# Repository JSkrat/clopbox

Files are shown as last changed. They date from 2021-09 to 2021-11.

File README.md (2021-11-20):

# clopbox
multiple power pwm outputs controlled with uart with runtime configurable waveform generators

## AVR fuses

By default only 3 outputs are working, so it is necessary to 

## Windows UART setup for speed

Device manager -> usb serial port -> properties -> port settings -> advanced -> BM options -> Latency timer -> set to minimum 1ms

This will reduce latency between actual response on uart and waitForReadyRead call in serialthread.cpp so minimal request period 
is about 8ms.

## The program can't start because Qt5Core.dll is missing from your computer.

Edit the system environment variables -> Environment Variables -> edit Path -> add `C:\Qt\5.12.5\mingw73_64\bin`

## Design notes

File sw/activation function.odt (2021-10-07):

Output power during the half period

Linear functions are boring, let’s curve it like that:

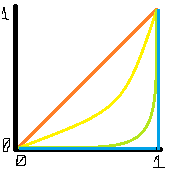
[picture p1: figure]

1. f(x) = x
2. …

### Rounding the curve

Let’s start from circle equation

left lbrace binom{x = r sin( %ialpha )}{y = r cos (%ialpha)} right rbrace

Move circle up

left lbrace binom{x = r sin(%ialpha)}{y = r - r cos(%ialpha)} right rbrace, %ialpha in [ %tau/2; %tau/4 ]

Convert into single function (red graph)

stack{sin( %ialpha ) = x/r; #
%ialpha = arcsin(x/r) #
y = r - r cos(arcsin(x/r)) #
cos(%ialpha ) = sqrt{ 1 - sin(%ialpha)^2 } #
y = r - r sqrt{ 1 - (x/r)^2 }
}

Let’s find the middle part of the curve we’re interested in (intersection with green line)

stack{
y = r - r sqrt{1 - (x/r)^2} intersection y = r - x #
r - r sqrt{1 - (x/r)^2} = r - x #
x = r sqrt{1 - (x/r)^2} #
x = sqrt{ r^2 - x^2 } #
x^2 = r^2 - x^2 #
2x^2 = r^2 #
x = r/sqrt2
}

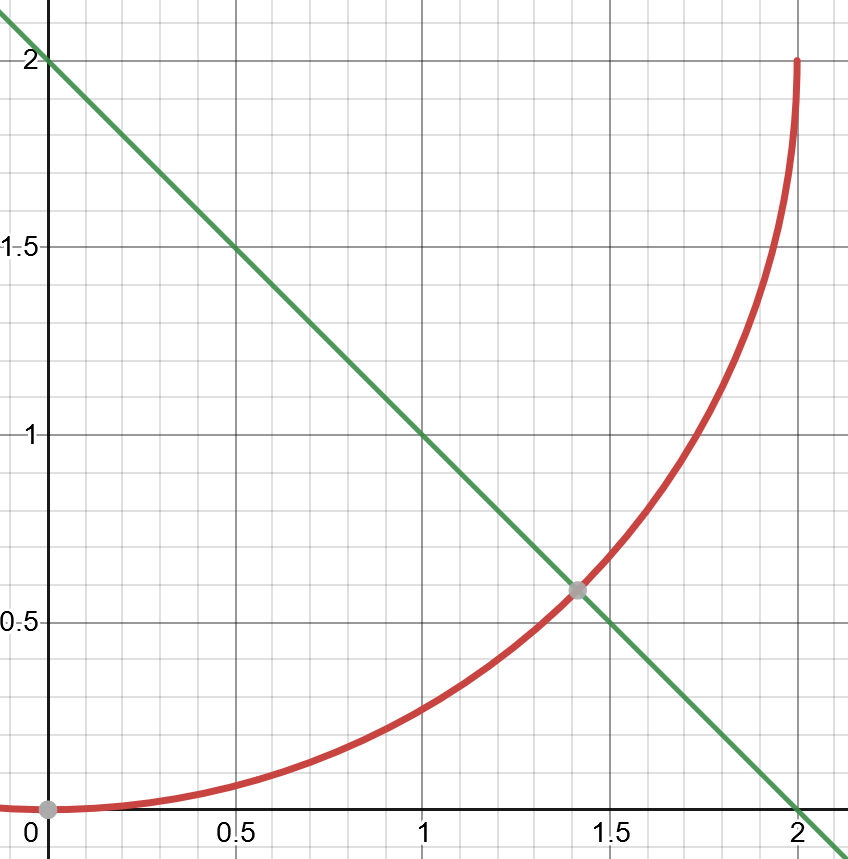
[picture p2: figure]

Apparently we don’t care about that intersection.

Intersection with y = x – b (yellow line)
stack{
y = r - r sqrt{1 - (x/r)^2} intersection y = x - b #
r - r sqrt{1 - (x/r)^2} = x - b #
r sqrt{ 1 - (x/r)^2 } = r + b - x #
r^2( 1 - (x/r)^2 ) = ( r+b )^2 - 2x( r+b ) + x^2 #
r^2 - x^2 = r^2 + 2rb + b^2 - 2xr - 2xb + x^2 #
2x^2 -2xb - 2xr + 2rb + b^2 = 0 #
2x^2 - 2x( r+b ) + (2rb+b^2) = 0 #
A = 2; B = -2r - 2b; C = 2rb + b^2 #
D = B^2 -4AC = 4( r+b )^2 - 4( 2 times (2rb + b^2) ) =
4r^2 + 8rb + 4b^2 - 16rb -8b^2 #
D = 4r^2 - 8rb - 4b^2 #
x_1,2 = {-B +-sqrt D}over {2A} #
x_1 = { 2r + 2b - sqrt{4r^2 - 8rb - 4b^2} } over 4 = 0.5r + 0.5b - 0.25sqrt{4r^2 - 8rb - 4b^2} #
x_2 = { 2r + 2b + sqrt{4r^2 - 8rb - 4b^2} } over 4 = 0.5r + 0.5b + 0.25sqrt{4r^2 - 8rb - 4b^2}

}

We need that line to intersect two points at distance exactly 1:

stack {
x_2 - x_1 = 1 #
0.5sqrt{4r^2 - 8rb - 4b^2} = 1 #
sqrt{4r^2 - 8rb - 4b^2} = 2 #
4r^2 - 8rb - 4b^2 = 4 #
4b^2 + 8rb - 4r^2 + 4 = 0 #
A = 4; B = 8r; C = 4 - 4r^2 #
D = 64r^2 - 4 times 4 times ( 4 - 4r^2 ) = 64r^2 - 64 + 64r^2 = 128r^2 - 64 #
b = {-8r +- sqrt{ 128r^2 - 64 }} over { 8 } = -r +- sqrt{ 2r^2 - 1 }
}

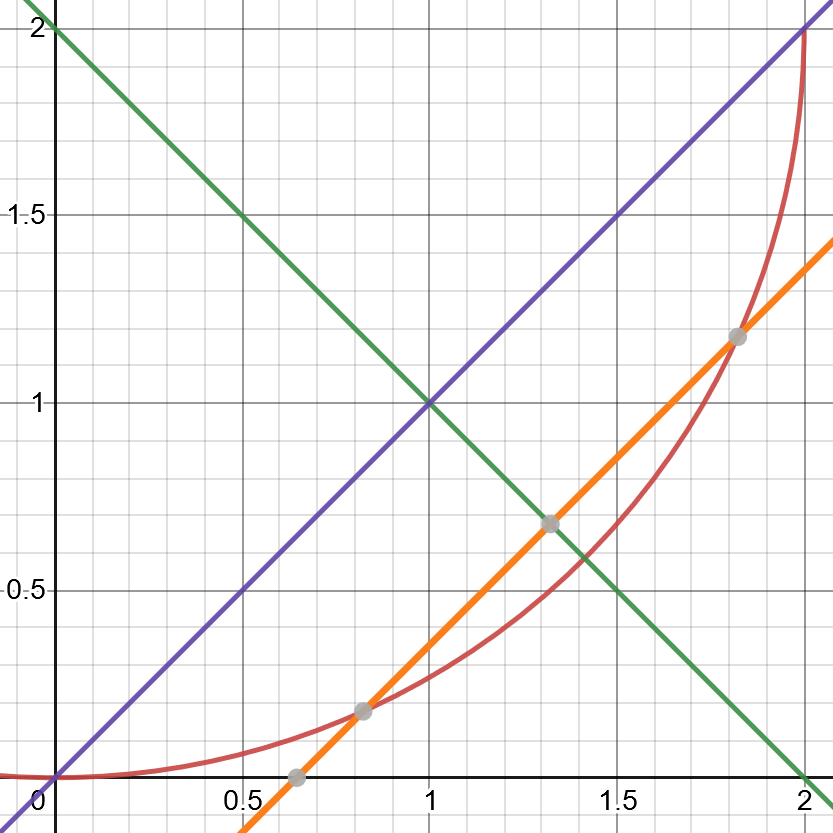
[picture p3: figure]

stack {
x_1 - x_2 = 1 #
-0.5sqrt{4r^2 - 8rb - 4b^2} = 1 #
sqrt{4r^2 - 8rb - 4b^2} = -2 #
4r^2 - 8rb - 4b^2 = 4 #
dotslow
}

We need smaller |b| from that, resulting in yellow line y = x – b

b = sqrt{ 2r^2-1 }-r

Now we need first intersection point with our circle (red curve), it will be our new zero: stack{
x_1 = 0.5r + 0.5b - 0.25 sqrt{ 4r^2 - 8rb - 4b^2 } #
b = sqrt{ 2r^2 - 1 } - r #
x_1 = 1/2r + 1/2 sqrt { 2r^2 - 1 } - 1/2r - 1/4 sqrt{ 4r^2 - 8r sqrt{2r^2 - 1} + 8r^2 - 4(sqrt{2r^2 - 1} - r)^2 } #
x_1 = 1/2 sqrt{ r^2 - 1 } - 1/4 sqrt{ 12r^2 - 8r sqrt{2r^2 - 1} - 4(2r^2-1 - 2r sqrt{2r^2 - 1} + r^2) } #
x_1 = 1/2 sqrt{ r^2 - 1 } - 1/4 sqrt{ 12r^2 - 8r sqrt{2r^ 2-1} - 8r^2 + 4 + 8r sqrt{2r^2-1} - 4r^2 } #
x_1 = 1/2sqrt{ 2r^2 - 1 } - 1/4sqrt{ 4 } = 1/2 sqrt{ 2r^2-1 } - 1/2
}

stack {
y_1 = r - r sqrt{ 1 - (x/r)^2 } = r - r sqrt{ 1 - {(1/2 sqrt{2r^2 - 1} - 1/2)^2} over r^2 } #
1/2 sqrt{ 2r^2 - 1 } = sqrt{1/2r^2 - 1/4} #
y_1 = r - r sqrt{ 1 - {1/2r^2 - 1/4 - sqrt{1/2r^2 - 1/4} + 1/4} over r^2 } #
y_1 = r - r sqrt{ {r^2 - 1/2r^2 + sqrt{1/2r^2 - 1/4}} over r^2 } = r - sqrt{ 1/2r^2 + sqrt{1/2r^2-1/4} }
}

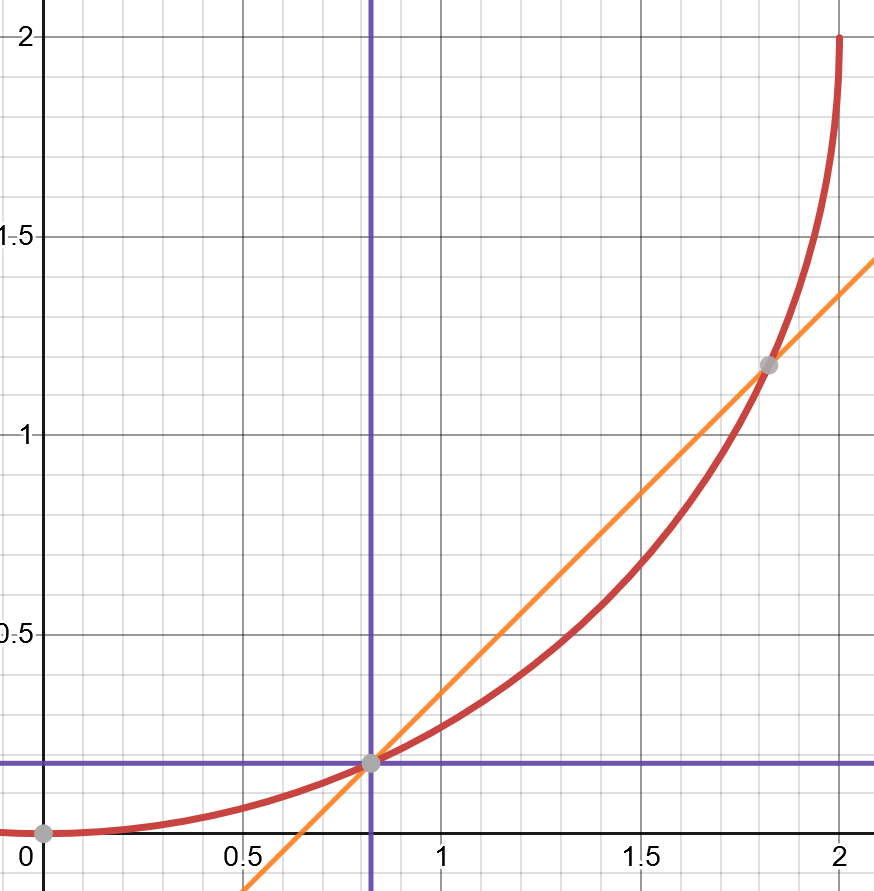
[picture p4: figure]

Now lets move our circle by those offsets

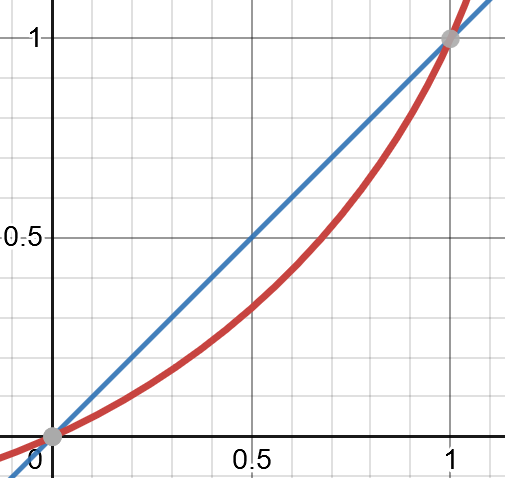
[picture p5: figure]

y = r - r sqrt{ 1 - ((x + x_1)/r)^2 } - y_1

Resources

1. Graph generator https://www.desmos.com/calculator

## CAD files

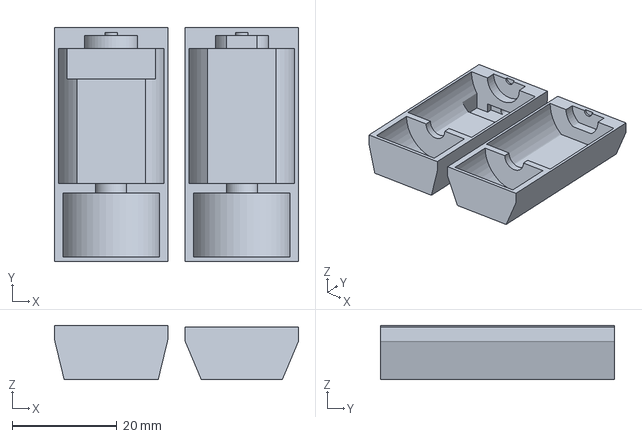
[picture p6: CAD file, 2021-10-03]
hw/engine casing.3mf
46.7 x 44.8 x 10.4 mm

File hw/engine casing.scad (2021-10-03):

$fn = 45;
t = 0.01;
clearance = 0.2;
wall = 0.9;


include <3d-stuff/engines.scad>;

module casing() {
    difference() {
        union() {
            linear_extrude(toy_engine_h_below + toy_engine_h_above + wall*2) {
                points = [
                    [7.75, toy_engine_depth/2 + wall + 1.7],
                    [toy_engine_width/2 + wall, 2.75],
                    [toy_engine_width/2 + wall, -2.75],
                    [9, -toy_engine_depth/2 - wall - 2]
                ];
                hull() // so we do not care about the order of points
                polygon([
                    for (x = [-1, 1]) 
                        //for (y = [-1, 1]) 
                            for (p = points) 
                                [p[0] * x, p[1] * 1]
                ]);
            }
        }
        translate([0, 0, toy_engine_h_below + wall])
        toy_engine(false);
        // space for wires
        wire_w = 10;
        wire_d = 2.4;
        wire_h = 1.5;
        wire_diameter = 1.5 + clearance*2;
        // wire hole to the bottom side
        translate([-wire_w/2, -toy_engine_depth/2 - wire_d, 4.1 - wire_h])
        cube([wire_w, wire_d, wire_h]);
        // hole for wires
        hull() {
            for (x = [-1, 1])
                translate([wire_diameter/2*x, -toy_engine_depth/2 - wire_diameter/2 - 0.5, -t])
                cylinder(d = wire_diameter, h = 4.1 - wire_h + t*2);
        }
        // wire hole to the back side
        /*rotate(90, [1, 0, 0])
        hull() {
            for (x = [-1, 1])
                translate([wire_diameter/2*x, 7, 0])
                cylinder(d = wire_diameter, h = toy_engine_depth);
        }*/
        translate([0, 0, toy_engine_h_below + wall + toy_engine_head_h])
        cylinder(r = 9 + clearance, h = toy_engine_h_above - toy_engine_head_h);
    }
}

*difference() {
    casing();
    //mirror([0, 1, 0])
    *translate([-100, 0, 0])
    cube([200, 200, 200]);
    translate([-100, -100, 9.8])
    cube([200, 200, 200]);
}

// parts are hardcoded to be on the same height
// print both halves on outside sides
rotate(90, [1, 0, 0]) {
    translate([0, 10.4, 0])
    difference() {
        casing();
        translate([-100, 0, -t])
        cube([200, 200, 200]);
    }

    translate([25, 10.1, 0])
    rotate(180, [0, 0, 1])
    difference() {
        casing();
        mirror([0, 1, 0])
        translate([-100, 0, -t])
        cube([200, 200, 200]);
    }
}

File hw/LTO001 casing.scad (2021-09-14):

$fn = 18;
// value for difference cuts
d = 0.005;
tolerance = 0.1;
b_tolerance = 0.3;
layer = 0.25;
wall = 2;
corner_r = 4;

cav_x = 123;
cav_y = 101;
cav_z_lower = 22.3;
cav_z_upper = 23;

module bolt_25() {
    color("silver") {
        cylinder(h = 1.8, d = 4.8);
        mirror([0, 0, 1])
        cylinder(h = 10, d = 1.5 + tolerance*2);
    }
}

module bolt_25_16() {
    color("silver") {
        cylinder(h = 1.8, d = 4.8);
        mirror([0, 0, 1])
        cylinder(h = 16, d = 1.5 + tolerance*2);
    }
}

module bolt_25_h() {
    color("#DE8") {
        mirror([0, 0, 1]) {
            cylinder(d1 = 4.8, d2 = 2.8, h = 1.4);
            translate([0, 0, 1.4])
            cylinder(d1 = 2.8, d2 = 2.0, h = 1.11);
            cylinder(h = 10, d = 1.5 + tolerance*2);        
        }
    }
}

module corner_cut(r, h) {
    difference() {
        translate([-r, -r, -d])
        cube([r*2, r*2, h+d*2]);
        for (x = [-r, r], y = [-r, r]) {
            translate([x, y, -d*2])
            cylinder(r = r, h = h + d*4);
        }
    }
}

module conn() {
    color("#2C6") {
        cube([7.8, 7.3, 9.5]);
        translate([0, -3.2, 9.5])
        cube([7.8, 11.5, 9]);
    }
    color("silver") {
        mirror([0, 0, 1]) {
            translate([1.9, 3.8, 0])
            cube([0.8, 0.8, 3.5]);
            translate([7.8-2.3-0.4, 3.8, 0])
            cube([0.8, 0.8, 3.5]);
        }
    }
}

module big_cap() {
    color("#080")
    cylinder(d = 10.1, h = 21);
}

module diode() {
    color("#333")
    cube([7.0, 6.0, 2.4]);
    color("silver")
    translate([-0.45, 1.5, 0])
    cube([7.9, 3, 1.4]);

}

module pcb(positive) {
    bolt_pos_x = [0.7+1.65, 118+1.65];
    bolt_pos_y = [0.9+1.65, 96.0+1.65];
    bolt_pos_z = [6, 0];
    pcb_h = 1;
    conn_h = 18.3+5;
    translate([0, 0, conn_h])
    if (! positive) {
        // pcb itself
        color("#0A2")
        difference() {
            cube([122, 100, pcb_h]);
            for (x = bolt_pos_x, y = bolt_pos_y) {
                translate([x, y, -d])
                cylinder(d = 3.3, h = pcb_h+d*2);
            }
        }
        translate([0, 0, pcb_h]) {
            // usb
            color("silver")
            translate([0, 67.6-12.1, 0])
            cube([16.5, 12.1, 11]);
            color("white")
            translate([0, 67.6-12.1, 0])
            mirror([1, 0, 0])
            cube([35, 12.1, 11]);
            // power
            color("#333")
            translate([0, 20, 0])
            cube([14, 9, 11.4]);
            color("#333")
            rotate(-90, [0, 1, 0])
            translate([13.3-11.2/2, 24.5, 0])
            cylinder(d = 11.2 + b_tolerance*2, h = 35);
            // bolts
            for (x = bolt_pos_x, y = bolt_pos_y) {
                if (y == bolt_pos_y[0]) {
                    translate([x, y, bolt_pos_z[0]])
                    bolt_25_16();
                    color([1, 1, 1, 0.5])
                    translate([x, y, 0])
                    cylinder(h = 6, d = 3.3);
                } else {
                    translate([x, y, bolt_pos_z[1]])
                    bolt_25();
                }
            }
            // big caps
            minkowski() {
                union() {
                    translate([22.7, 13.5, 0])
                    big_cap();
                    translate([22.7, 25.2, 0])
                    big_cap();
                    // diode
                    translate([14.4, 0.6, 0])
                    diode();
                }
                sphere(r = b_tolerance, $fn = 9);
            }
        }
        // connectors
        minkowski() {
            for (x = [28.7: 11.35714: 116]) {
                mirror([0, 0, 1])
                translate([x, 5.4, 0])
                conn();
            }
            sphere(r = b_tolerance, $fn=9);
        }
        color([1, 1, 1, 0.5])
        translate([20, -10, -conn_h-d])
        cube([87+9.2, 25 + 10, conn_h+d + d]);
        /*translate([122-6, 0, -1])
        cube([6, 12, 1]);*/
    } else {
        // holders
        for (x = bolt_pos_x, y = bolt_pos_y) {
            color("#333")
            translate([x, y, -d])
            cylinder(d = 3.3 - tolerance*2, h = pcb_h + d*2);
            color("#333")
            translate([x, y, 0])
            mirror([0, 0, 1])
            cylinder(d = 9, h = conn_h);
        }
    }
}

module side(d_fit) {
    w = cav_y + wall*2 + d*2;
    h = cav_z_lower + wall + d*2;
    w_bolt = 10;
    r = 2;
    offset = w*0.29;
    minkowski() {
        union() {
            difference() {
                square([w, h]);
                for (y = [0, offset, w - offset, w]) {
                    translate([y, 0])
                    circle(r = cav_z_lower*0.85);
                }
                square([w, r+1]);
            }
            translate([w/2 - w_bolt/2, r+1])
            square([w_bolt, h - r*2 - 1]);
        }
        circle(r = r + d_fit);
    }
}

module screw_pillar_vertical(screw_d, screw_l, screw_r) {
    cylinder(d = screw_d, h = screw_l);
    translate([0, 0, screw_l])
    scale([1, 1, screw_r/screw_d*2])
    sphere(d = screw_d);
}

module screw_pillar() {
    screw_d = 10;
    screw_l = 10;
    screw_r = 2;
    translate([0, 0, screw_d/2]) {
        rotate(90, [0, 1, 0]) {
            screw_pillar_vertical(screw_d, screw_l, screw_r);
        }
        translate([0, 0, -screw_d/2])
        linear_extrude(screw_d/2) {
            projection(cut = false) {
                rotate(90, [0, 1, 0]) {
                    screw_pillar_vertical(screw_d, screw_l, screw_r);
                }                
            }
        }
    }
}

module box_lower(positive, demo) {
    padding = 0.5;
    d_fit = (positive)? tolerance: -tolerance;
    difference() {
        union() {
            difference() {
                translate([-wall + d_fit, 0, 0])
                color("#333")
                cube([cav_x + wall*2 + wall*2 - d_fit*2, cav_y + wall*2, cav_z_lower + wall]);
                // main cavity
                color("#333")
                translate([wall, wall, wall])
                cube([cav_x, cav_y, cav_z_lower + tolerance]);
            }
            // walls for the connectors
            color("#333")
            cube([cav_x + wall*2, 27.5 + wall, cav_z_lower - 2.5 - 1]);
            // pcb holders
            translate([wall+padding, wall+padding, 0])
            pcb(true);
            // for screws
            translate([wall, (cav_y + wall*2)/2, 0])
            screw_pillar();
            translate([wall + cav_x, (cav_y + wall*2)/2, 0])
            mirror([1, 0, 0])
            screw_pillar();
        }
        translate([wall+padding, wall+padding, 0])
        pcb(false);
        // slots for cap
        for (y = [-d, cav_y + wall*1.5 -d_fit]) {
            translate([-d - wall, y, cav_z_lower + wall/2 - d_fit*0])
            cube([d*2 + cav_x + wall*4, wall/2 + d_fit + d, wall/2 + d_fit*0 + d]);
        }
        // cuts for cap slides
        for (x = [-wall-d+d_fit, cav_x + wall*2 + d - d_fit]) {
            translate([x, -d, -d])
            rotate(90, [0, 0, 1])
            rotate(90, [1, 0, 0])
            linear_extrude(wall) side(d_fit);
        }
        // holes for screws
        translate([-wall, cav_y/2 + wall, wall+4])
        rotate(-90, [0, 1, 0])
        bolt_25_h();
        translate([cav_x + wall*3, cav_y/2 + wall, wall+4])
        rotate(90, [0, 1, 0])
        bolt_25_h();
        // hanging thingy
        translate([18 - d_fit, -d, cav_z_lower])
        cube([105 + d_fit*2, wall +d*2, wall + d]);
    }
    if (demo || ! positive) {
        translate([wall+padding, wall+padding, 0])
        pcb(false);
        translate([-wall, cav_y/2 + wall, wall+4])
        rotate(-90, [0, 1, 0])
        bolt_25_h();
        translate([cav_x + wall*3, cav_y/2 + wall, wall+4])
        rotate(90, [0, 1, 0])
        bolt_25_h();
    }
}

module cap() {
    c = [0.25, 0.18, 0.25, 0.7];
    difference() {
        color(c)
        translate([-wall+d, d, d])
        cube([cav_x + wall*4-d*2, cav_y + wall*2-d*2, cav_z_lower + cav_z_upper + wall*2 - d]);
        color(c)
        translate([-d, wall-d, -d])
        cube([cav_x + wall*2 +d*2, cav_y+d*2, cav_z_lower + cav_z_upper + d]);
        box_lower(false, false);
    }
}

module lower_cap() {
    difference() {
        cube([cav_x + wall*2, cav_y + wall*2, wall]);
        translate([0, 0, -d])
        box_lower(false, false);
    }
}

module bracket(demo) {
    difference() {
        translate([0, 0, 24.3])
        union() {
            cube([122, 8, 6-d]);
            translate([0, 6, 6])
            cube([122, 2, 6]);
        }
        pcb(false);
    }
    if (demo) {
        pcb(false);
    }
}

box_lower(true, false);
cap();
bracket(false);

*difference() {
    box_lower(true, false);
    translate([-d, cav_y/2 + wall, -d])
    cube([cav_x + wall*4 + d*2, cav_y, cav_z_lower + wall +d*2]);
}

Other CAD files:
hw/engine casing.stl

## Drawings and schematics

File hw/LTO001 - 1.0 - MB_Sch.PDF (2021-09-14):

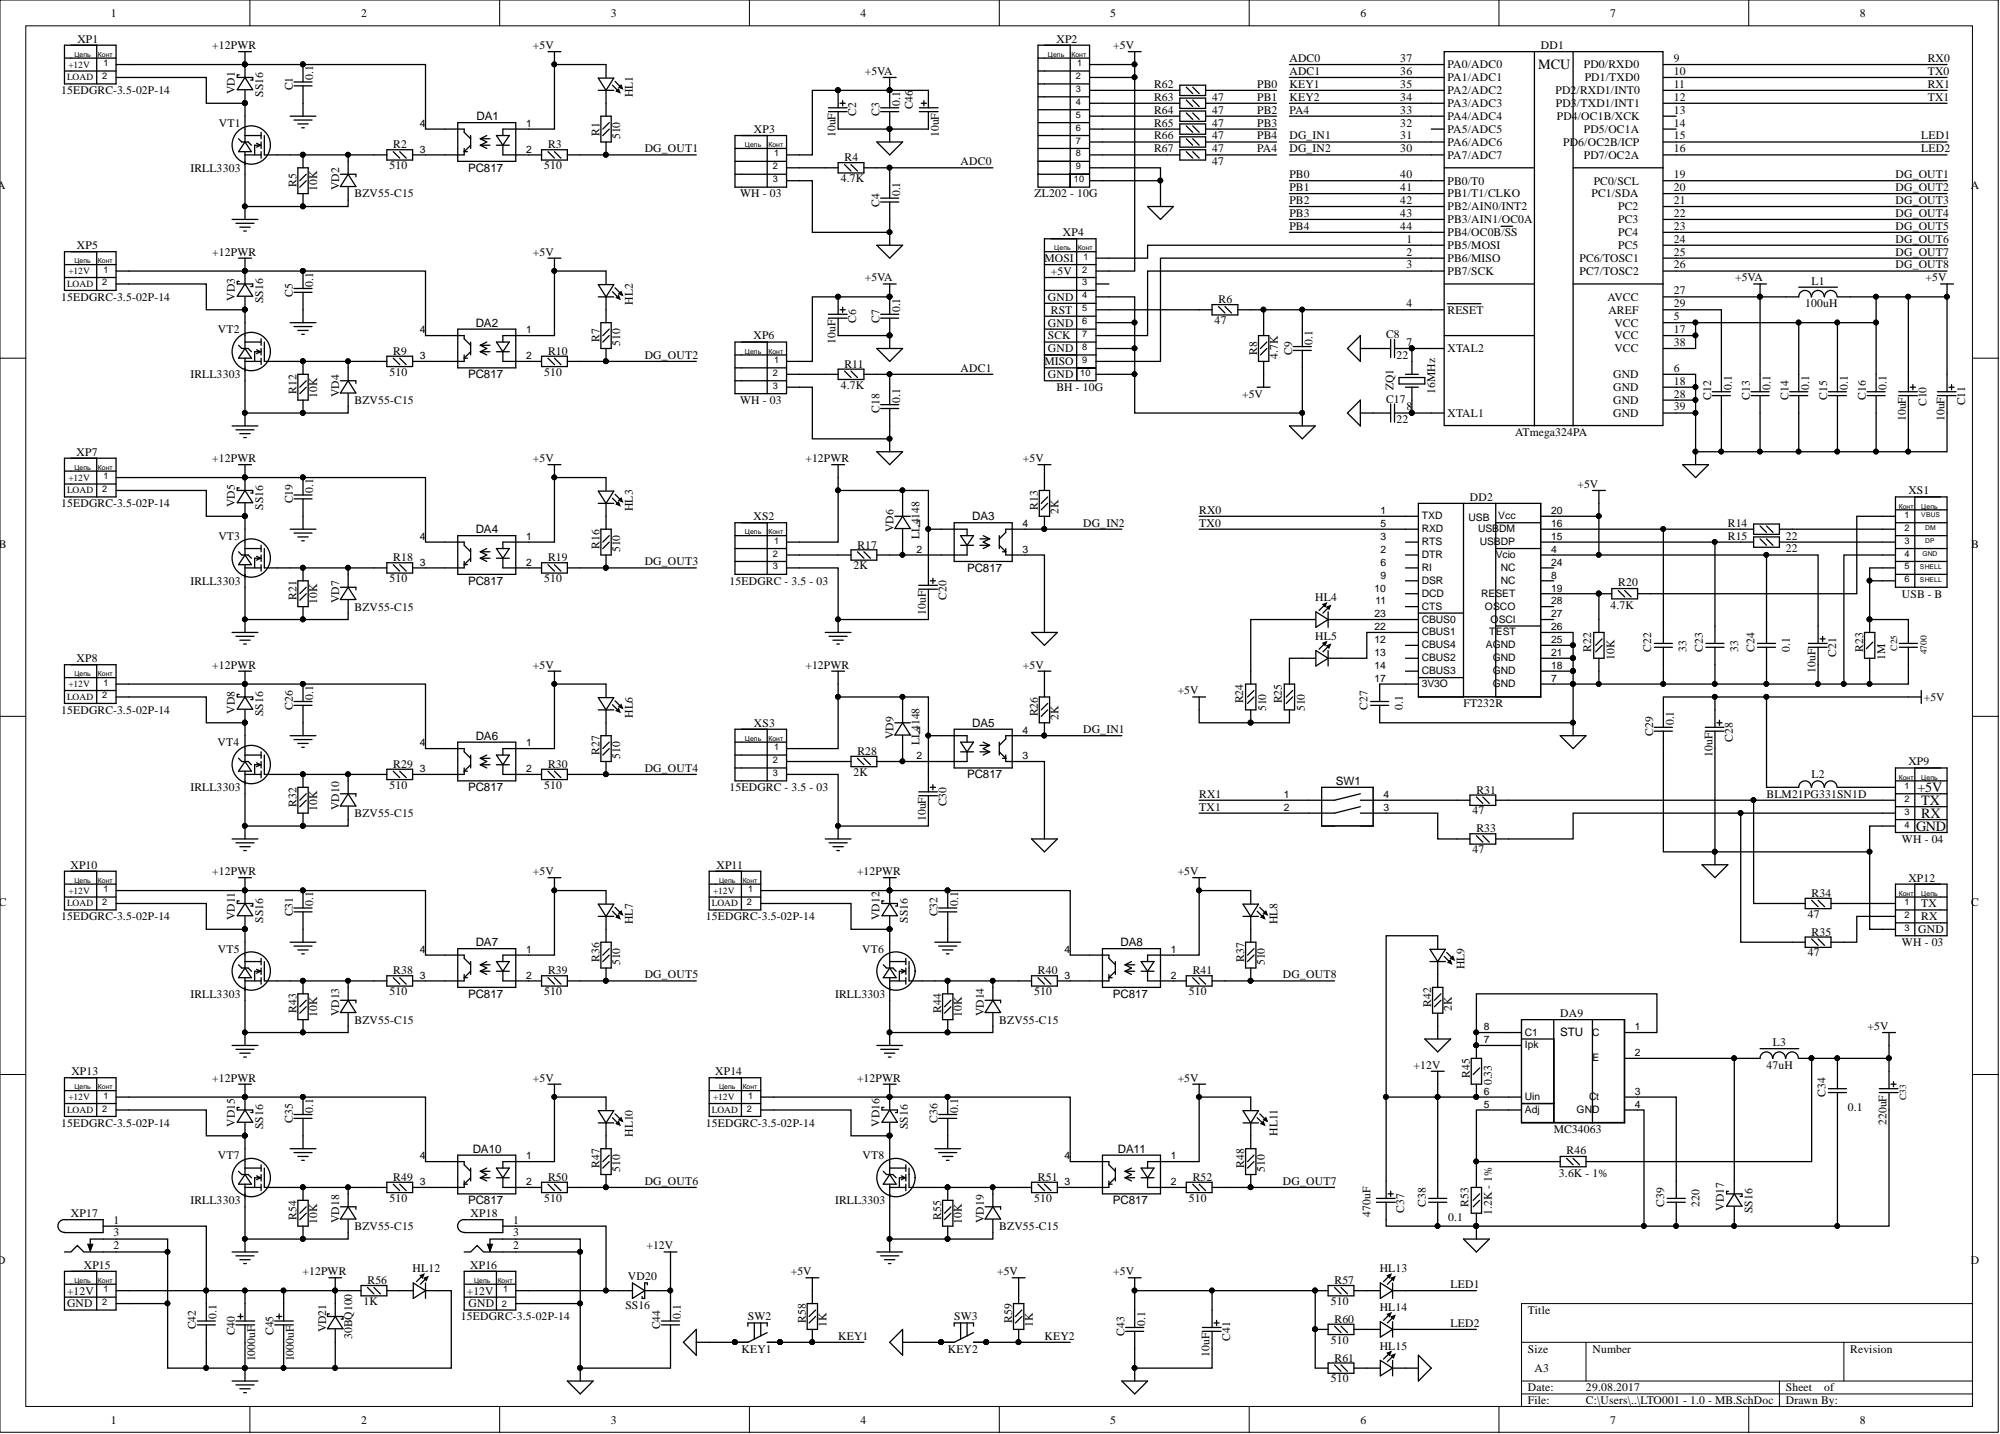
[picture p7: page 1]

Цеп ь | Кон т

PA 0 / A DC0 PA 1 / A DC1 PA 2 / A DC2 PA 3 / A DC3 PA 4 / A DC4 PA 5 / A DC5 PA 6 / A DC6 PA 7 / A DC7 | PD PD | PD 0 /RX D 0 PD 1 / T X D 0 2 /RX D 1 /IN T 0 3 / T X D 1 /IN T 1 4 / OC1B/ XCK PD 5 / OC1 A 6 / OC2B/ICP PD 7 / OC2 A

R6 3 | K E Y 2 3 4
R6 4 | PA 4 3 3
R6 5 | 3 2 D G _IN 1 3 1
R6 6
R6 7 | D G _IN 2 3 0

PB0 / T 0 PB1 / T 1 /CL K O PB2 / AIN 0 /IN T 2 PB3 / AIN 1 / OC0 A PB4 / OC0B/SS PB5 /MOSI PB6 /MISO PB7 /SCK | PC0 /SCL PC1 /SD A PC2 PC3 PC4 PC5 PC6 / T OSC1 PC7 / T OSC2

2 9
1 7

4 | 2 2
2 4 9 | 0

2 2 | | 2
1 2 1 3 | | | 2 5

4 | | 1 8
7 | G N D | 7

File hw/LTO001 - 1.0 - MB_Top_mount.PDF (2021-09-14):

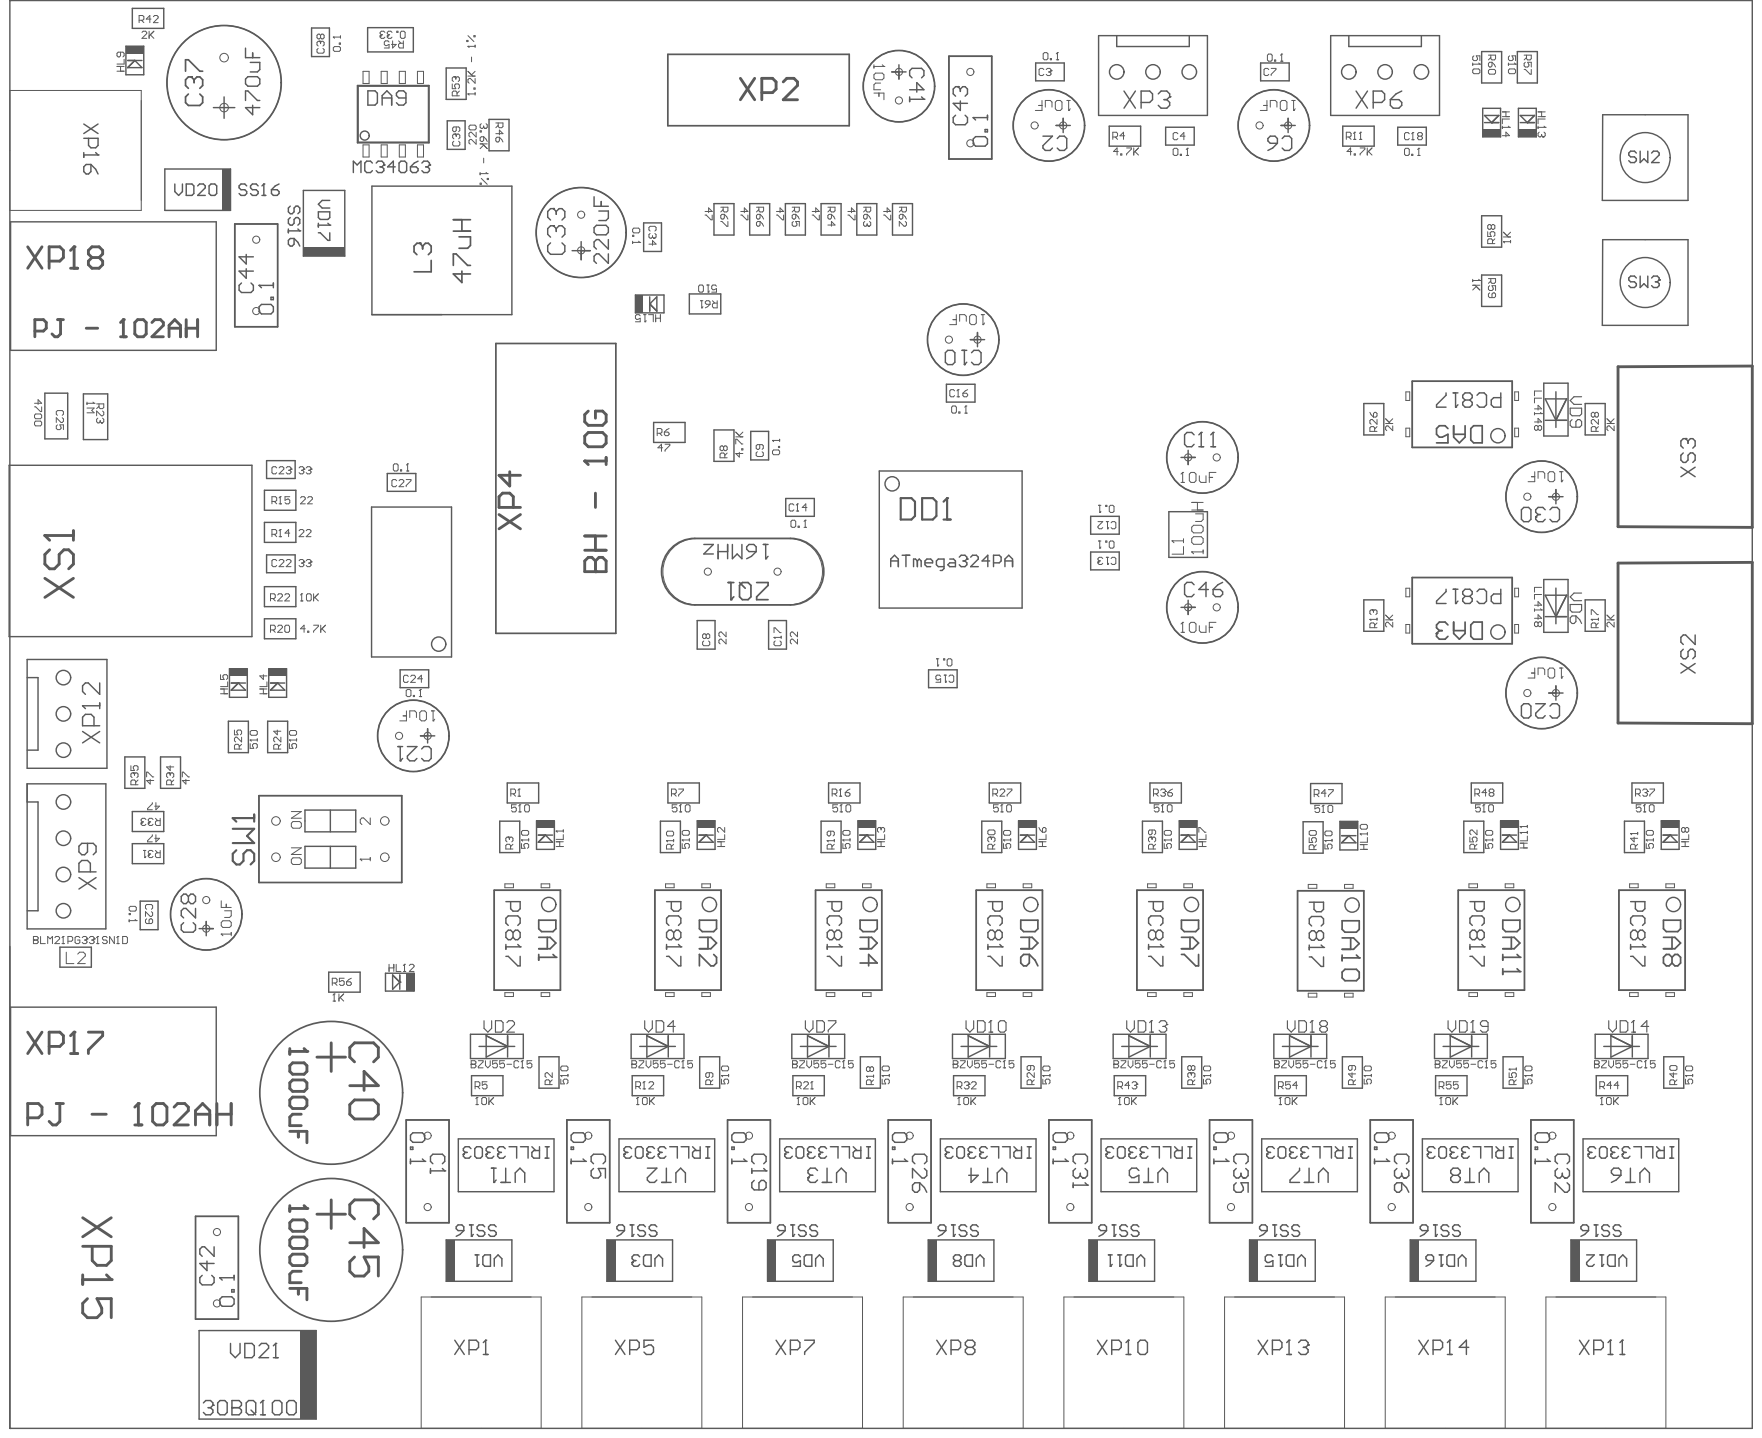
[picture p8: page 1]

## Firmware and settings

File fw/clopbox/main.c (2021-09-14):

/*
 * clopbox.c
 *
 * Created: 22.05.2021 14:10:44
 * Author : Mintytail
 */ 

#include <avr/io.h>
#include <avr/interrupt.h>
#include "data.h"
#include "hardware.h"
#include "uart.h"


int main(void)
{
	data_init();
	hardware_init();
	uart_init();
	for (int i = 0; i < output_num; i++) {
		outputs[i] = 0;
	}
	sei();
    /* Replace with your application code */
    while (1) 
    {
    }
}

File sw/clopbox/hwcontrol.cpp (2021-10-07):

#include "hwcontrol.h"
#include "serialthread.h"
#include <QJsonArray>
#include <QJsonValue>
#include <QJsonObject>
#include <QJsonDocument>
#include <QFile>
#include <QCoreApplication>
#include <QString>
#include <iostream>
#include <QVariant>
#include "exceptions.h"
#include "hwoutput.h"
#include "waveform.h"


void HwControl::_validateOutputNumber(int outputNumber)
{
    if (0 > outputNumber) throw LogException(error, QString("output can not be negative (%1)").arg(outputNumber));
    if (OUTPUT_NUM <= outputNumber) throw LogException(error, QString("output can not be bigger than %1 (%2)").arg(OUTPUT_NUM).arg(outputNumber));
}

HwControl::HwControl(QObject *parent, QString mappingFile, QString port) :
    QObject(parent), serial(this), portName(port), uartTimeout(4), uartErrors(0), uartTimeouts(0)
{
    qRegisterMetaType<uint8_t>("uint8_t");
    connect(&(this->serial), &SerialThread::response, this, &HwControl::serialResponse);
    connect(&(this->serial), &SerialThread::timeout, this, &HwControl::serialTimeout);
    connect(&(this->serial), &SerialThread::error, this, &HwControl::serialError);
    QFile outputsConfig(mappingFile);
    if (!outputsConfig.open(QIODevice::ReadOnly)) {
        std::cerr << QString("Retrieving driver mapping QFile error: %1").arg(outputsConfig.errorString()).toStdString().c_str();
        QCoreApplication::exit(outputsConfig.error());
    }
    QJsonDocument outputs = QJsonDocument::fromJson(outputsConfig.readAll());
    QJsonArray outputsArray = outputs.array();
    outputsConfig.close();
    int i = 0;
    for (QJsonValue outputJsonValue: outputsArray) {
        if (OUTPUT_NUM <= i) {
            std::cerr << "too much outputs in outputs.json, ignoring extra" << std::endl;
            break;
        }
        QVariantMap output = outputJsonValue.toObject().toVariantMap();
        //std::cout << output["name"].toString().toStdString().c_str() << std::endl;
        this->_outputs[i] = {
            .name = output["name"].toString(),
            .enabled = output["enabled"].toBool(),
            .lastOutput = 0,
            .hwOutput = 0,
            .output = new HwOutput(
                this,
                output["power factor"].toFloat(),
                output["start time"].toFloat(),
                output["start power"].toInt(),
                output["minimal power"].toInt()
            ),
            .generator = new WaveForm(),
        };
        i++;
    }
    this->_outputUpdateTime.start();
    // one period of the device is 64ms, but to avoid interference patters let's peek couple times smaller
    this->_outputUpdateTimer.setInterval(16);
    connect(&(this->_outputUpdateTimer), &QTimer::timeout, this, &HwControl::outputUpdate);
    this->_outputUpdateTimer.start();
}

float HwControl::getOutput(int outputNumber)
{
    this->_validateOutputNumber(outputNumber);
    return this->_outputs[outputNumber].output->getPower();
}

void HwControl::setOutput(int outputNumber, float power)
{
    this->_validateOutputNumber(outputNumber);
    this->_outputs[outputNumber].output->setPower(power);
}

WaveForm *HwControl::generator(int output)
{
    this->_validateOutputNumber(output);
    return this->_outputs[output].generator;
}

QString HwControl::getName(int outputNumber)
{
    this->_validateOutputNumber(outputNumber);
    return this->_outputs[outputNumber].name;
}

/// returns the real value from the device, [0:1]
float HwControl::getDeviceOutput(int outputNumber)
{
    this->_validateOutputNumber(outputNumber);
    return this->_outputs[outputNumber].hwOutput;
}

int HwControl::getQueueLength()
{
    return this->serial.getQueueSize();
}

void HwControl::serialResponse(const uint8_t command, const uint8_t code, const QByteArray &response)
{
    eUARTFunction eCommand = static_cast<eUARTFunction>(command);
    if (0 != code) {
        std::cerr << "HwControl::serialResponse not good code "
                  << static_cast<int>(code)
                  << " command "
                  << static_cast<int>(command)
                  << std::endl;
    }
    switch (eCommand) {
    case ufGetOutputs: {
        if (8 != response.length()) return;
        for (int i = 0; i < response.length(); i++) {
            this->_outputs[i].hwOutput = this->_outputs[i].output->parsePower(response[i]);
        }
        break;
    }
    case ufSetOutputs: {

        break;
    }
    case ufResetOutputs: {
        break;
    }
    case ufSetOutput: {
        break;
    }
    case ufSetOutputWithTimeout: {
        break;
    }
    default: {
        break;
    }
    }
}

void HwControl::serialTimeout(const QString &message)
{
    std::cerr << "HwControl::serialTimeout " << message.toStdString() << std::endl;
    this->uartTimeouts++;
}

void HwControl::serialError(const QString &message)
{
    std::cerr << "HwControl::serialError " << message.toStdString() << std::endl;
    this->uartErrors++;
}

void HwControl::outputUpdate()
{
    // command length is 12 bytes, it is 120 bits, it is 1.042ms@115200
    QByteArray outputs;
    const TTime timePassed = this->_outputUpdateTime.restart();
    for (int i = 0; i < OUTPUT_NUM; i++) {
        this->_outputs[i].output->setPower(
            this->_outputs[i].generator->calculateNextStep(timePassed)
        );
        TPower output = this->_outputs[i].output->calculateNextStep(timePassed);
        outputs.append(output);
        this->_outputs[i].lastOutput = output;
    }
    this->_serialTransaction(ufSetOutputs, outputs);
    this->_serialTransaction(ufGetOutputs, {});
}

void HwControl::_serialTransaction(eUARTFunction command, QByteArray data)
{
    data.prepend(command);
    this->serial.transaction(this->portName, this->uartTimeout, data);
}

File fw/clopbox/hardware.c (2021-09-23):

/*
 * hardware.c
 *
 * Created: 22.05.2021 17:59:12
 *  Author: Mintytail
 * we're taking PORTC as output of all 8 outlets
 * is not designed for more than 8 outputs!
 *
 * pwm period is 1kHz with 64 levels
 * 
 */ 

#include <stdint.h>
#include <avr/interrupt.h>
#include <stdbool.h>
#include "data.h"

static uint8_t phase = 0;

void hardware_init() {
	// disable external clock to enable PORTC7
	ASSR &= ~(1 << EXCLK) & ~(1 << AS2);
	// setup all outputs
	DDRC = 0xFF;
	// setup a timer
	// mode CTC, clear after TCNT2 == OCR2A
	TCCR2A = (1 << WGM21) | (0 << WGM20);
	// prescaling 1, frequency 62500, 256 timer, period 976.5625Hz
	TCCR2B = (0 << CS22) | (0 << CS21) | (1 << CS20) | (0 << WGM22);
	// make it 1kHz exactly to count milliseconds as well
	OCR2A = 250-1;
	// enable overflow interrupt
	TIMSK2 = (1 << OCIE2A);
}


ISR(TIMER2_COMPA_vect) {
	phase += 1;
	if (64 <= phase) {
		phase = 0;
		// decrement once per period, so it is a milliseconds
		// TODO it appears it is once per 64ms, so it is in 64ms chunks
		/*for (int i = 0; i < output_num; i++) {
			if (outputs_timers[i]) {
				outputs_timers[i] -= 1;
			}
		}*/
	}
	uint8_t output = 0;
	bool i_output;
	for (int i = 0; i < output_num; i++) {
		output <<= 1;
		/*if (outputs_timers[i]) {
			i_output = outputs_timers_powers[i] <= phase;
		} else {*/
			i_output = outputs[i] <= phase;
		//}
		if (i_output) output |= 1;
	}
	PORTC = output;
}

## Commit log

2021-09-14 add box
    [LTO001 casing.scad]
2021-09-23 sw: hwcontrol now updates outputs to the uart
2021-09-25 sw: create ui, link ui to control, improve serialthread error messages for timeout
    [hwcontrol.cpp, serialthread.cpp]
2021-09-25 fw: bugfix, allow power level 63
    [uart functions.c]
2021-09-25 sw: add serial queue length to statusbar, reduce delays, fix power and startup sequence
    [hwcontrol.cpp]
2021-09-25 sw: add about uart setup for windows in readme
2021-09-26 sw: add digits for power level, add prototype for waveform generator
2021-10-02 hw: add casing for engine
    [engine casing.scad]
2021-10-03 hw: move wire holes to the edge for easier insert from inside add stl and slice just in case
    [engine casing.3mf, engine casing.scad, engine casing.stl]
